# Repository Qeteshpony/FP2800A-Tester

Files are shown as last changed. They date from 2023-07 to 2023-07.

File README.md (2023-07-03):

# FP2800A-Tester



3D Render

[Hardware Documentation](https://qeteshpony.github.io/FP2800A-Tester)

Arduino Uno compatible shield for testing functionality of a FP2800A

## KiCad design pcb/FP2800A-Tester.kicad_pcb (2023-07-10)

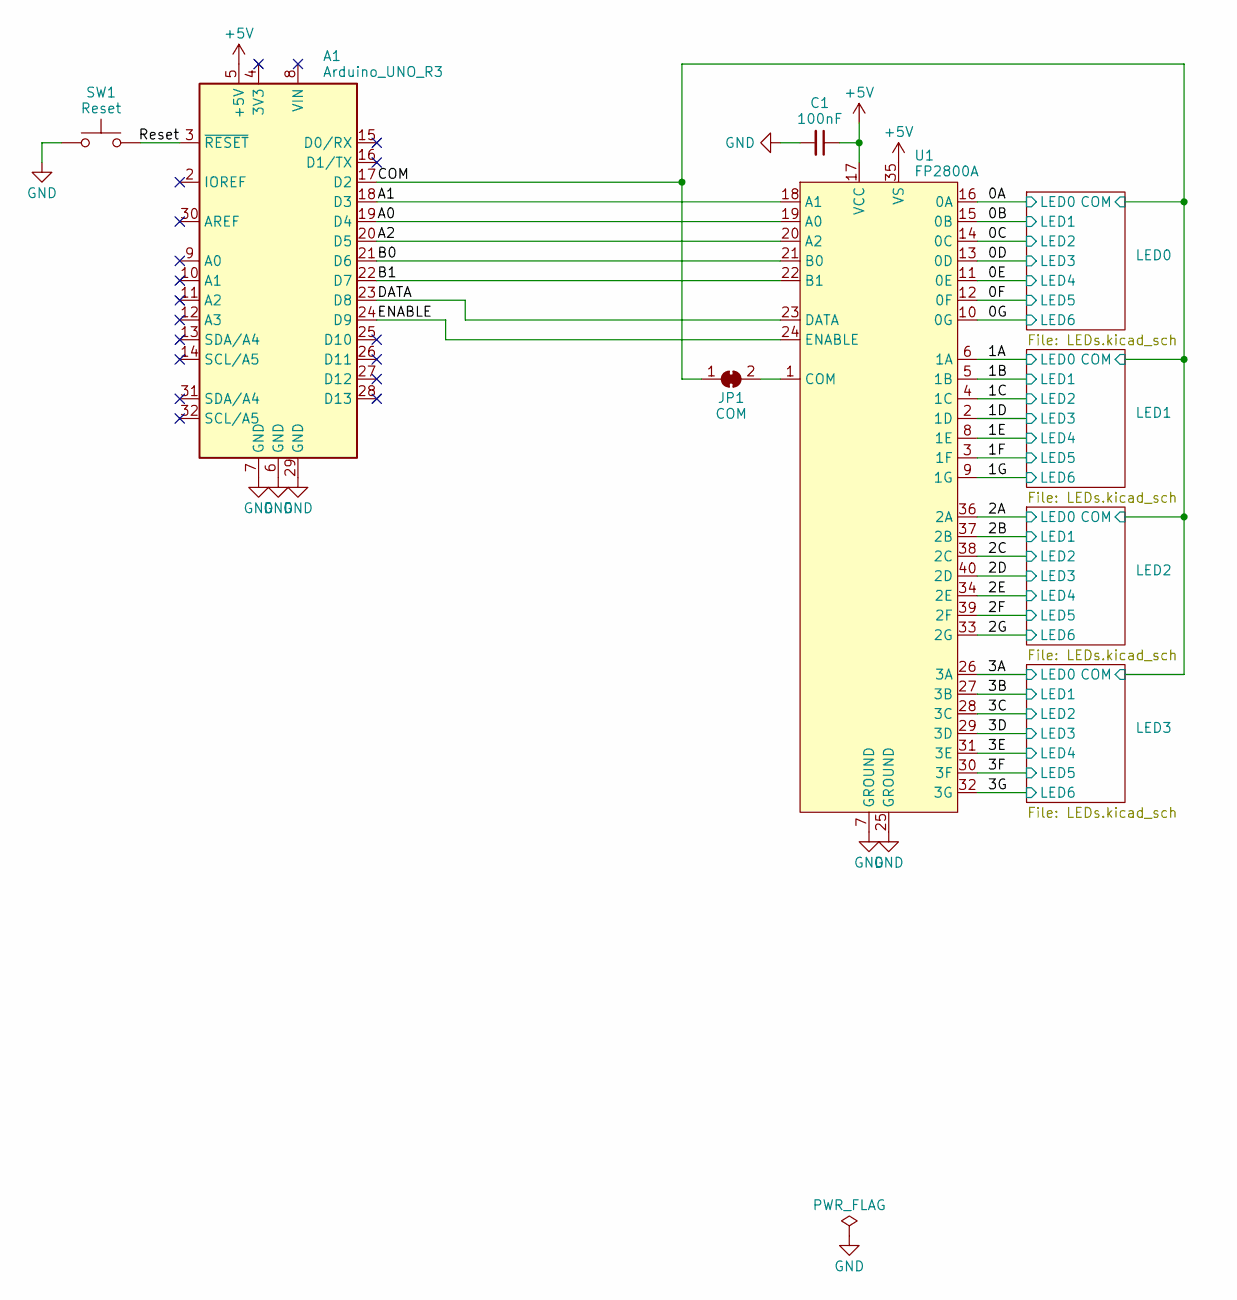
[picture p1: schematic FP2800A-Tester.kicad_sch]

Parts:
A1: Arduino_UNO_R3
C1: 100nF; C_0603_1608Metric; LCSC C14663
JP1: COM; SolderJumper-2_P1.3mm_Bridged_RoundedPad1.0x1.5mm
SW1: Reset; SW_PUSH_6mm
U1: FP2800A; DIP_Socket-40_W11.9_W12.7_W15.24_W17.78_W18.5_3M_240-1280-0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

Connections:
+5V: A1.5 (+5V), C1.1, U1.17 (VCC), U1.35 (VS)
/0A: U1.16 (0A); also elsewhere on the board
/0B: U1.15 (0B); also elsewhere on the board
/0C: U1.14 (0C); also elsewhere on the board
/0D: U1.13 (0D); also elsewhere on the board
/0E: U1.11 (0E); also elsewhere on the board
/0F: U1.12 (0F); also elsewhere on the board
/0G: U1.10 (0G); also elsewhere on the board
/1A: U1.6 (1A); also elsewhere on the board
/1B: U1.5 (1B); also elsewhere on the board
/1C: U1.4 (1C); also elsewhere on the board
/1D: U1.2 (1D); also elsewhere on the board
/1E: U1.8 (1E); also elsewhere on the board
/1F: U1.3 (1F); also elsewhere on the board
/1G: U1.9 (1G); also elsewhere on the board
/2A: U1.36 (2A); also elsewhere on the board
/2B: U1.37 (2B); also elsewhere on the board
/2C: U1.38 (2C); also elsewhere on the board
/2D: U1.40 (2D); also elsewhere on the board
/2E: U1.34 (2E); also elsewhere on the board
/2F: U1.39 (2F); also elsewhere on the board
/2G: U1.33 (2G); also elsewhere on the board
/3A: U1.26 (3A); also elsewhere on the board
/3B: U1.27 (3B); also elsewhere on the board
/3C: U1.28 (3C); also elsewhere on the board
/3D: U1.29 (3D); also elsewhere on the board
/3E: U1.31 (3E); also elsewhere on the board
/3F: U1.30 (3F); also elsewhere on the board
/3G: U1.32 (3G); also elsewhere on the board
/A0: A1.19 (D4), U1.19 (A0)
/A1: A1.18 (D3), U1.18 (A1)
/A2: A1.20 (D5), U1.20 (A2)
/B0: A1.21 (D6), U1.21 (B0)
/B1: A1.22 (D7), U1.22 (B1)
/COM: A1.17 (D2), JP1.1 (A); also elsewhere on the board
/DATA: A1.23 (D8), U1.23 (DATA)
/ENABLE: A1.24 (D9), U1.24 (ENABLE)
/Reset: A1.3 (~RESET), SW1.2
GND: A1.6 (GND), A1.7 (GND), A1.29 (GND), C1.2, SW1.1, U1.7 (GROUND), U1.25 (GROUND)
unnamed: JP1.2 (B), U1.1 (COM)

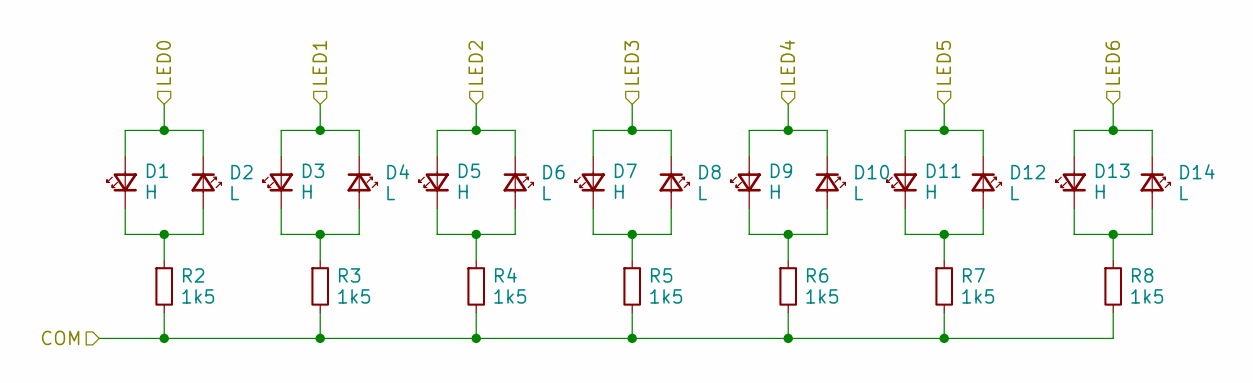
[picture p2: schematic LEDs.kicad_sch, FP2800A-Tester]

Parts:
D1, D3, D5, D7, D9, D11, D13: H; LED_0603_1608Metric; LCSC C72043
D2, D4, D6, D8, D10, D12, D14: L; LED_0603_1608Metric; LCSC C2286
R2, R3, R4, R5, R6, R7, R8: 1k5; R_0603_1608Metric; LCSC C22843

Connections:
/0A: D1.2 (A), D2.1 (K); also elsewhere on the board
/0B: D3.2 (A), D4.1 (K); also elsewhere on the board
/0C: D5.2 (A), D6.1 (K); also elsewhere on the board
/0D: D7.2 (A), D8.1 (K); also elsewhere on the board
/0E: D9.2 (A), D10.1 (K); also elsewhere on the board
/0F: D11.2 (A), D12.1 (K); also elsewhere on the board
/0G: D13.2 (A), D14.1 (K); also elsewhere on the board
/COM: R2.2, R3.2, R4.2, R5.2, R6.2, R7.2, R8.2; also elsewhere on the board
unnamed: D1.1 (K), D2.2 (A), R2.1
unnamed: D3.1 (K), D4.2 (A), R3.1
unnamed: D5.1 (K), D6.2 (A), R4.1
unnamed: D7.1 (K), D8.2 (A), R5.1
unnamed: D9.1 (K), D10.2 (A), R6.1
unnamed: D11.1 (K), D12.2 (A), R7.1
unnamed: D13.1 (K), D14.2 (A), R8.1

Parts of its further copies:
D15, D17, D19, D21, D23, D25, D27, D29, D31, D33, D35, D37, D39, D41, D43, D45, D47, D49, D51, D53, D55: H; LED_0603_1608Metric; LCSC C72043
D16, D18, D20, D22, D24, D26, D28, D30, D32, D34, D36, D38, D40, D42, D44, D46, D48, D50, D52, D54, D56: L; LED_0603_1608Metric; LCSC C2286
R9, R10, R11, R12, R13, R14, R15, R16, R17, R18, R19, R20, R21, R22, R23, R24, R25, R26, R27, R28, R29: 1k5; R_0603_1608Metric; LCSC C22843

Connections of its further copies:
/1A: D15.2 (A), D16.1 (K); also elsewhere on the board
/1B: D17.2 (A), D18.1 (K); also elsewhere on the board
/1C: D19.2 (A), D20.1 (K); also elsewhere on the board
/1D: D21.2 (A), D22.1 (K); also elsewhere on the board
/1E: D23.2 (A), D24.1 (K); also elsewhere on the board
/1F: D25.2 (A), D26.1 (K); also elsewhere on the board
/1G: D27.2 (A), D28.1 (K); also elsewhere on the board
/2A: D29.2 (A), D30.1 (K); also elsewhere on the board
/2B: D31.2 (A), D32.1 (K); also elsewhere on the board
/2C: D33.2 (A), D34.1 (K); also elsewhere on the board
/2D: D35.2 (A), D36.1 (K); also elsewhere on the board
/2E: D37.2 (A), D38.1 (K); also elsewhere on the board
/2F: D39.2 (A), D40.1 (K); also elsewhere on the board
/2G: D41.2 (A), D42.1 (K); also elsewhere on the board
/3A: D43.2 (A), D44.1 (K); also elsewhere on the board
/3B: D45.2 (A), D46.1 (K); also elsewhere on the board
/3C: D47.2 (A), D48.1 (K); also elsewhere on the board
/3D: D49.2 (A), D50.1 (K); also elsewhere on the board
/3E: D51.2 (A), D52.1 (K); also elsewhere on the board
/3F: D53.2 (A), D54.1 (K); also elsewhere on the board
/3G: D55.2 (A), D56.1 (K); also elsewhere on the board
/COM: R9.2, R10.2, R11.2, R12.2, R13.2, R14.2, R15.2, R16.2, R17.2, R18.2, R19.2, R20.2, R21.2, R22.2, R23.2, R24.2, R25.2, R26.2, R27.2, R28.2, R29.2; also elsewhere on the board
unnamed: D15.1 (K), D16.2 (A), R9.1
unnamed: D17.1 (K), D18.2 (A), R10.1
unnamed: D19.1 (K), D20.2 (A), R11.1
unnamed: D21.1 (K), D22.2 (A), R12.1
unnamed: D23.1 (K), D24.2 (A), R13.1
unnamed: D25.1 (K), D26.2 (A), R14.1
unnamed: D27.1 (K), D28.2 (A), R15.1
unnamed: D29.1 (K), D30.2 (A), R16.1
unnamed: D31.1 (K), D32.2 (A), R17.1
unnamed: D33.1 (K), D34.2 (A), R18.1
unnamed: D35.1 (K), D36.2 (A), R19.1
unnamed: D37.1 (K), D38.2 (A), R20.1
unnamed: D39.1 (K), D40.2 (A), R21.1
unnamed: D41.1 (K), D42.2 (A), R22.1
unnamed: D43.1 (K), D44.2 (A), R23.1
unnamed: D45.1 (K), D46.2 (A), R24.1
unnamed: D47.1 (K), D48.2 (A), R25.1
unnamed: D49.1 (K), D50.2 (A), R26.1
unnamed: D51.1 (K), D52.2 (A), R27.1
unnamed: D53.1 (K), D54.2 (A), R28.1
unnamed: D55.1 (K), D56.2 (A), R29.1

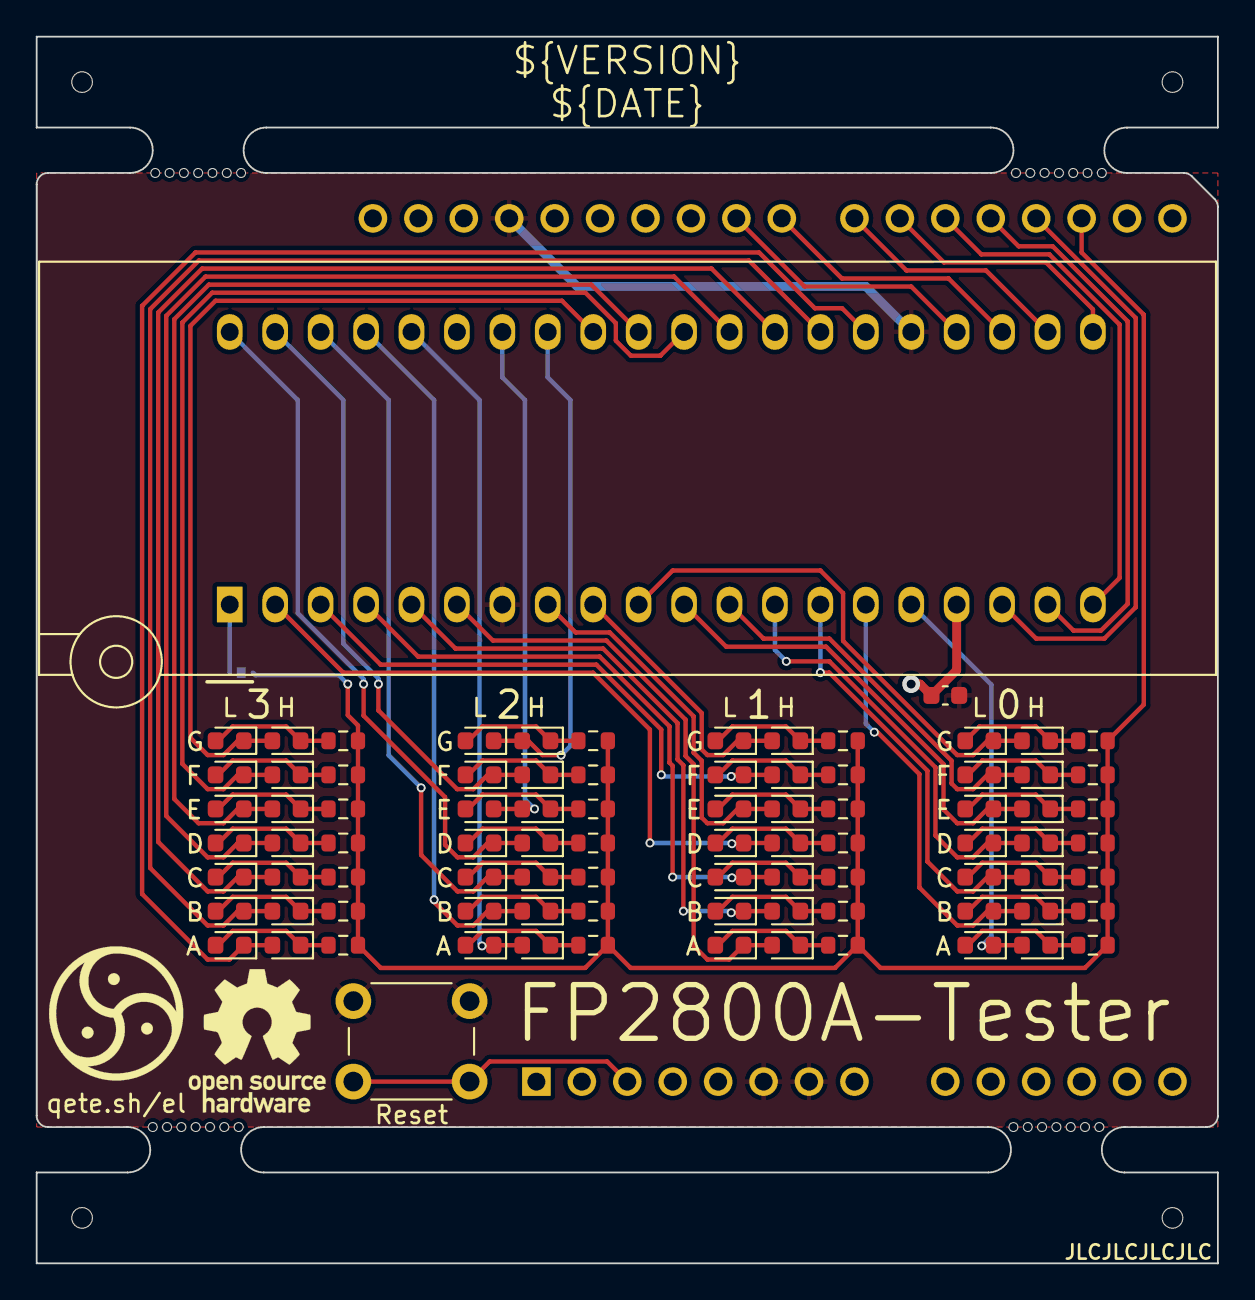
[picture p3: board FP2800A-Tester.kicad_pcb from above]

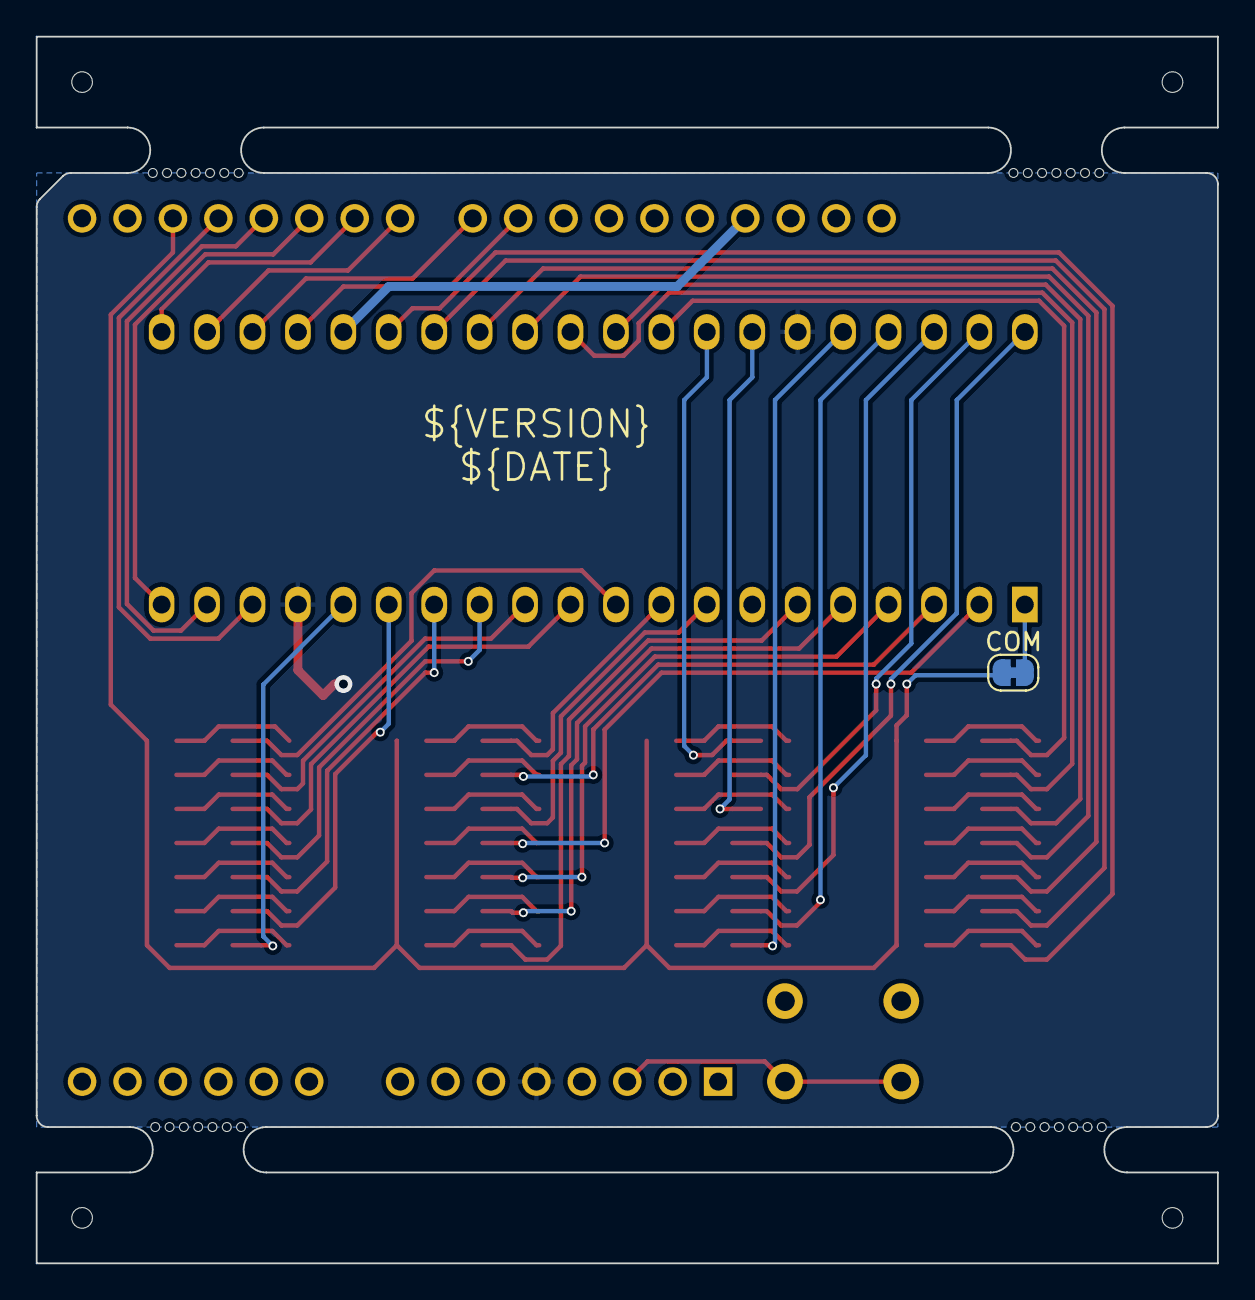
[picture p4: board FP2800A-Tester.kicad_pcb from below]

Board: 2 copper layers, 66.0 x 68.6 mm, 89 parts (2 on the bottom side), 68 nets.

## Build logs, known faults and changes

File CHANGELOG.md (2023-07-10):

# Changelog

## [1.2.0](https://github.com/Qeteshpony/FP2800A-Tester/compare/v1.1.0...v1.2.0) (2023-07-10)

### Features

* initial code release ([a889a49](https://github.com/Qeteshpony/FP2800A-Tester/commit/a889a4943077f3e11daa80d03d439bba2450b33b))
* replace IC socket with ZIF socket ([89d4ad5](https://github.com/Qeteshpony/FP2800A-Tester/commit/89d4ad598d1a1bd65329efb8804e9976bacfe1aa))

### Bug Fixes

* turn the loops around ([66abdb0](https://github.com/Qeteshpony/FP2800A-Tester/commit/66abdb034dc38ca23341db6be017dc87a18b23f6))

## [1.1.0](https://github.com/Qeteshpony/FP2800A-Tester/compare/v1.0.0...v1.1.0) (2023-07-04)

### Features

* add COM Jumper ([9bb217a](https://github.com/Qeteshpony/FP2800A-Tester/commit/9bb217a832c6b033c05825b5408a660720be3de0))

## 1.0.0 (2023-07-03)

### Features

* add part numbers for production ([cb1af00](https://github.com/Qeteshpony/FP2800A-Tester/commit/cb1af00a4c233a9bd24167824745c3fde0aa9ce1))
* add rails ([5f07b53](https://github.com/Qeteshpony/FP2800A-Tester/commit/5f07b53c4e94078d8e5bf5e92b2097cdbb3aa467))
* initial commit ([5538093](https://github.com/Qeteshpony/FP2800A-Tester/commit/5538093a1120296208a0bdb66c94712f0a2a65d4))

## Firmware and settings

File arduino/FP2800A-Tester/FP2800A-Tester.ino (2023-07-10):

// pin definitions
#define FPA0      4
#define FPA1      3
#define FPA2      5
#define FPB0      6
#define FPB1      7
#define FPDATA    8
#define FPENABLE  9
#define COM       2

void setup() {
  // start serial 
  Serial.begin(2000000);  //this speed only works with Arduino IDE 2.x or an external serial monitor. Use 115200 for older IDEs

  // initialize pins
  pinMode(FPA0, OUTPUT);
  pinMode(FPA1, OUTPUT);
  pinMode(FPA2, OUTPUT);
  pinMode(FPB0, OUTPUT);
  pinMode(FPB1, OUTPUT);
  pinMode(FPDATA, OUTPUT);
  pinMode(FPENABLE, OUTPUT);
  pinMode(COM, INPUT);  // only needed as output if the COM pin on the FP2800A doesn't work 
}

void loop() {
  // Toggle data pin for each loop so we switch between positive and negative output
  bool data = !digitalRead(FPDATA);
  digitalWrite(FPDATA, data);

  // Loop through all the outputs and enable one after another
  int a, b;
  char buf[10];
  for (b = 3; b >= 0; b--) {  
    digitalWrite(FPB0, (b >> 0) % 2);
    digitalWrite(FPB1, (b >> 1) % 2);
    for (a = 7; a >= 1; a--) {
      sprintf(buf, "%d, %d = %d", b, a, data);  
      Serial.println(buf);
      digitalWrite(FPA0, (a >> 0) % 2);
      digitalWrite(FPA1, (a >> 1) % 2);
      digitalWrite(FPA2, (a >> 2) % 2);
      digitalWrite(FPENABLE, 1);
      delayMicroseconds(100);  // use for inspection of all pins at once
      //delay(250); // use for visual inspection of each output
      digitalWrite(FPENABLE, 0);
    }
  }
}

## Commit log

2023-07-03 feat: initial commit
    [FP2800A-Tester.kicad_pcb, FP2800A-Tester.kicad_sch, LEDs.kicad_sch]
2023-07-03 style: add variables
    [FP2800A-Tester.kicad_pcb, FP2800A-Tester.kicad_sch, LEDs.kicad_sch]
2023-07-03 feat: add rails
    [FP2800A-Tester.kicad_pcb]
2023-07-03 feat: add part numbers for production
    [FP2800A-Tester.kicad_pcb, FP2800A-Tester.kicad_sch, LEDs.kicad_sch]
2023-07-03 style: schematics cleanup
    [FP2800A-Tester.kicad_sch, LEDs.kicad_sch]
2023-07-04 feat: add COM Jumper
    Add a jumper that allows to disconnect the FP2800A COM pin from the LEDs
    [FP2800A-Tester.kicad_pcb, FP2800A-Tester.kicad_sch]
2023-07-10 fix: turn the loops around
    Making the loops count down instead of up to make the LED light up in a nicer order. Also added some comments
    [FP2800A-Tester.ino]
2023-07-10 feat: replace IC socket with ZIF socket
    [FP2800A-Tester.kicad_pcb, FP2800A-Tester.kicad_sch]
